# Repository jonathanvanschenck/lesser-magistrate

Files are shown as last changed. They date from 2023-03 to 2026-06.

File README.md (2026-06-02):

#  The Lesser Magistrate
A collection of Electrical and Mechanical Schematics for the IOC Lesser Magistrate Quizzing System

Schematics, PCB Files, BOM and 3D printing files are [available here](https://github.com/jonathanvanschenck/lesser-magistrate).

To find more information or get involved with Christian Bible Quizzing (CBQ), [click here](https://cbqz.org).

## Philosophy of Design
Heretofore, bible quizzing has had a fairly high barrier to entry; whether it be complicated rulebooks, distinct cultural practices or (of relevance here) expensive supplies. This project
seeks to address that third barrier by providing a low-cost, high-performance quizzing buzzer system, which can built by a reasonably competent individual. Unlike existing systems, we need
to meet the following design requirements:

  - Low cost and easily available parts
  - Easily manufactureable without special tooling
  - Is modular in design (e.g. individual components are easily and cheaply replaceable)
  - Can support up to 15 simultaneous participants

## Build Instructions
A Lesser Magistrate set can be built with a varying number of triggers depending on your needs. Throughout this documentation, examples are given for three common configurations:

- **16 triggers** — the maximum supported: 3 teams of 5 quizzers each, plus 1 trigger reserved for the quiz magistrate.
- **10 triggers** — the typical arrangement for a CBQ quiz: 3 teams of 3 quizzers each, plus 1 for the quiz magistrate.
- **12 triggers** — a 10-trigger set with 2 spares, useful to have on hand in case of hardware failure during a tournament.

If you have recieved a build kit, you should already have all the raw materials to build a lesser magistrate, including electrical components, 3d printed enclosures and hardware. In this case, you will only need a few tools to help during the build:
  - A Soldering Iron (literally anything will work here -- you don't need to spend tons of money on this unless you plan to make a lot of units)
  - Lead-free Solder (Again, literally anything will work here -- the amount of soldering on the project is pretty small so you won't run out)
  - Allen Wrench
  - Phillips head screw driver (long shaft)

### Video Guides and Examples

There is a video guide you can follow for step-by-step instructions on how to build your Lesser Magistrate system:

- https://www.youtube.com/watch?v=u-B20jy8v2o&list=PL-Vn05Kf5ezxIfupx7_Z1d6l5HKGBeLW2

Here are additional example videos:

- https://youtu.be/reuCWvhqvTU
- https://youtu.be/7Vi3QWguprs
- https://youtu.be/mlhh7Sf7_HU
- https://youtu.be/uHA6wKbFMOs
- https://youtu.be/KhpSTn409PQ
- https://youtu.be/kogF7mJOyTQ

### Electrical Schematics

All electrical schematics are available in the [graphics](./graphcis) directory, which can be helpful during assembly, particularly for those who are more electrically inclined.

There are some additional tools which are very helpful during the build process; but are not strictly necessary:
  - Some elmers glue, or similar light adhesive
  - The assembly jigs, [see the 3d printer directory for details](./3d)

If you are interested in purchasing a Lesser Magistrate system (or any of the necessary components -- particularly the PCBs), contact [the author](https://github.com/jonathanvanschenck).

If you did *not* receive a kit, the next section will explain how to acquire all the necessary raw components.

### Ordering the Components Yourself
If you did not receive kit, you will need to acquire the raw materials. Broadly there are 3 categories of things you will need to purchase:

#### 1. Electrical Component
You will need to buy all the electrical components (meaning chips, resistors, connectors and wires). See the [components README](./components/README.md) for full part lists and Digikey shopping links for 16, 12, and 10 trigger set configurations.

#### 2. PCB
You will also need to buy the actual PCBs to soulder everything to. You can find the gerber files (the extension is `.zip`) in the `gerber` directory, with a [README](./gerber/README.md) for details. You can use any PCB manufacturer you prefer, for example [PCBWay](https://www.pcbway.com/) -- in every case you cant just upload your gerber files and the website will walk you through the steps. Two things to note: (1) make sure to select HASL lead-free surface treatment to avoid lead exposure, use defaults for everything else (2) you will likely be required to order at least 5 of every board; but the boards are sufficiently cheap that shipping is frequently the majority of the PCB cost even when over-buying boards.

#### 3. Plastic Enclosures
You will also need to get plastic enclosures for all the electrical elements. All of this is done with a 3d printer. Many schools and libraries have 3d printers available to the students/members, so try asking around in your community to see if someone has access to a printer to help with this piece. There are also plenty of online services that you can upload a file to and have them print and ship it to you. Though, if you plan on making more than, like, 2 of these units -- just get a printer yourself. They are pretty cheap these days, can you can do a lot with them. Both [Bambu Labs](https://bambulab.com/en-us) and [Prusa Reaserch](https://www.prusa3d.com/) have mid-level and high-end hobbyist models in the $500-$1500 range.

However you plan on getting your prints, you will need the STL files in the [stl](./stl) directory -- see the README there for details.

## Contributing and Development
The Lesser Magistrate is a fully open sourced project, and as such contribution is encouraged! As such PRs are more than welcome, and we would love to hear about [any issues](https://github.com/jonathanvanschenck/lesser-magistrate/issues) you may run into. Feature requests are also encouraged -- though keep in mind features will only be included in this project if they conform to the Philosophy of Design described above. Finally, if you take this project and do something cool with it (like adding extra features not suitable to this design philosophy), we would love to hear about it so that we can add a link to your work in the section below!

Currently the electrical side of the project is developed in [diptrace](https://diptrace.com/), and all the project files are in the [lib](./lib) directory. That being said, we are in the process of converting to KiCAD as the development tool, and also creating a SMD-variant of the LM/LMM/Trigger boards which will facilitate a pick-n-place machine assembly; so don't get too attached to diptrace.

## Related Projects

## Deuteronomy 6:5-7
Love the Lord your God with all your heart and with all your soul and with all your strength.
These commandments that I give you today are to be on your hearts.
Impress them on your children. Talk about them when you sit at home and when you walk along the road, when you lie down and when you get up.

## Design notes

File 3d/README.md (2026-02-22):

# Enclosures and Construction Assests
This subdirectory contains all the stl files for the plastic enclosures for the electronics as well as jigs for assembly.

An STL file is the standard format used in the 3d printing world. So, if you are ordering out these parts, you can provide these STLs and
your manufacturer will know what to do with them.

Note, each set of files will create a single instance of whatever you are printing. So, for example, you will need a barrel, cap and stablizer to make 1 trigger. So if you want 16 triggers, you will need 16 stablizers, caps and barrrels.

## STL Files
The STL files for all 3d printed parts can be found in the `stl` folder. Contained are:
  - Enclosures:
    - LM Box:
        - [Top](./stl/LMBottom.stl)
        - [Bottom](./stl/LMBottom.stl)
    - LLM Box:
        - [Top](./stl/LMMTop.stl)
        - [Bottom](./stl/LLMBottom.stl)
    - Trigger:
        - [Barrel](./stl/TriggerBottom.stl)
        - [Cap](./stl/TriggerCap.stl): Important Note! You might need to scale this part up/down by a few percent during slicing so that you achieve an interference fit with the barrel.
        - [Stabilizer](./stl/TriggerStablizer.stl)
  - Jigs: These are optional assembly jigs, which are very nice if you are make many sets all together
    - [Board holder](./stl/LMConstructionBoardHolder.stl): used to hold the PCB in place while soldering.
    - Trigger jig:
        - [Anvil](./stl/TriggerConstructionAnvil.stl): creates a flat surface for the trigger to be pressed against.
        - [Ram](./stl/TriggerConstructionRam.stl): used to press the cap onto the barrel without hurting your hands.

When generating gcode with your slicer, it is recommended to use 0.2mm accuracy, rectilinear infill at 20% and print using PLA. Additionally, the trigger's cap may need to be scaled slightly (a few percent) in your slicer to achieve a good interference fit with the barrel.

## Quantities by Trigger Set

The number of printed parts depends on how many triggers you are building. Enclosure quantities scale with triggers; jigs are optional and quantity depends on your workflow.

### Enclosures

| STL File | 16 Trigger Set | 12 Trigger Set | 10 Trigger Set | Explanation |
|---|:---:|:---:|:---:|---|
| [LM Box Top](./stl/LMTop.stl) | 1 | 1 | 1 | One per set — top half of the main controller enclosure |
| [LM Box Bottom](./stl/LMBottom.stl) | 1 | 1 | 1 | One per set — bottom half of the main controller enclosure |
| [LMM Box Top](./stl/LMMTop.stl) | 3 | 3 | 3 | One per team (3 teams in every configuration) |
| [LMM Box Bottom](./stl/LLMBottom.stl) | 3 | 3 | 3 | One per team (3 teams in every configuration) |
| [Trigger Barrel](./stl/TriggerBottom.stl) | 16 | 12 | 10 | One per trigger |
| [Trigger Cap](./stl/TriggerCap.stl) | 16 | 12 | 10 | One per trigger — may need slight scaling for interference fit |
| [Trigger Stabilizer](./stl/TriggerStablizer.stl) | 16 | 12 | 10 | One per trigger |

### Assembly Jigs (Optional)

| STL File | Suggested Qty | Explanation |
|---|:---:|---|
| [Board Holder](./stl/LMConstructionBoardHolder.stl) | 1 | Holds the PCB steady during soldering; one is sufficient for any set size |
| [Trigger Jig Anvil](./stl/TriggerConstructionAnvil.stl) | 1 | Flat surface for pressing caps onto barrels; one is sufficient |
| [Trigger Jig Ram](./stl/TriggerConstructionRam.stl) | 1 | Used with the anvil to press caps without hand strain; one is sufficient |

Contact [the author](https://github.com/jonathanvanschenck/) for further details.

## CAD Files
The full CAD files can be found on onshape:
  - [The main box](https://cad.onshape.com/documents/543b25c417126967cb08de50/v/1616035887736616c0c97bd4/e/729fc64504c2a798e70d9855).
  - [The module](https://cad.onshape.com/documents/a71d7e6c5d369e82da67ce55/v/a1a71b7b6bb9f6b15cbdba2f/e/51fbe87dbc7215f3dbb1e72c).
  - [The trigger](https://cad.onshape.com/documents/fc78aac2c958586ca1177853/w/f2e33e2147721cb4fc4541b8/e/58d502121f0acd43c261de76).
  - [Trigger jig](https://cad.onshape.com/documents/b3dc0fd1912a70c055d7c740/w/58a53ed1eda9de1b411d2abd/e/50ec51447436c03dc649d699)
  - [Board holder jig](https://cad.onshape.com/documents/089ddd3080857b092a4a133b/w/d44446d03ada5b263a56f82f/e/a523e0c8f14e67229ecee9d0)

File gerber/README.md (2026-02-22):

# Gerber Files
In this directory are the gerber files (extension `.zip`) for the PCBs used in this project.

A gerber file is really just a zip file containing all the information necessary for a PCB manufacturer to create your PCB. Any boardhouse will know what to do with a gerber file.

Note, each file will create only a single instance of whatever it contains. So, for example, if you order "a LMM board" from the gerber file, you will get exactly 1 PCB, where a typical set requires 3. So, you will want to make sure your quantities are corrected when ordering.

## Gerber files
  - [LM Board](./LMGerber.zip)
  - [LMM Board](./LMMGerber.zip)
  - [Trigger Board](./TriggerGerber.zip)

## Quantities by Trigger Set

The number of PCBs you need to order depends on how many triggers you are building. There is always 1 LM (main controller) board and 1 LMM (module) board per team. The number of Trigger boards equals the total number of triggers.

| Gerber File | 16 Trigger Set | 12 Trigger Set | 10 Trigger Set | Explanation |
|---|:---:|:---:|:---:|---|
| [LM Board](./LMGerber.zip) | 1 | 1 | 1 | One per set — the main quiz magistrate controller board |
| [LMM Board](./LMMGerber.zip) | 3 | 3 | 3 | One per team |
| [Trigger Board](./TriggerGerber.zip) | 16 | 12 | 10 | One per trigger |

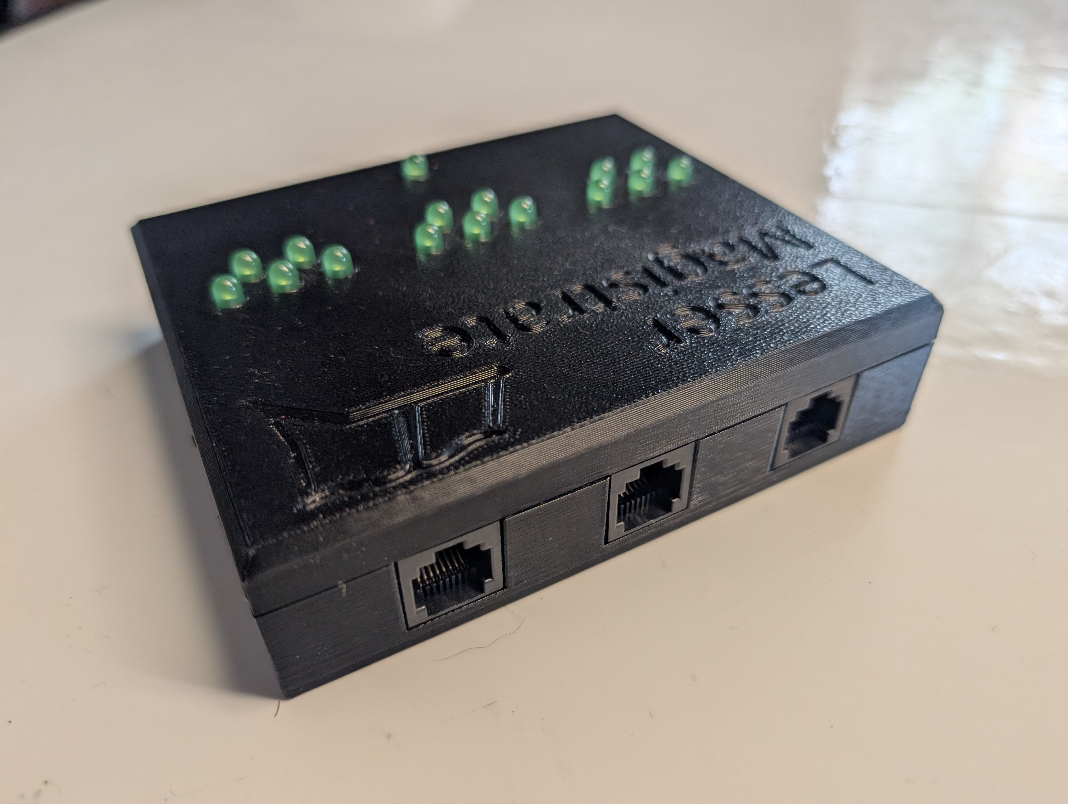
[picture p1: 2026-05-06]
images/2_lm_console_back.jpg

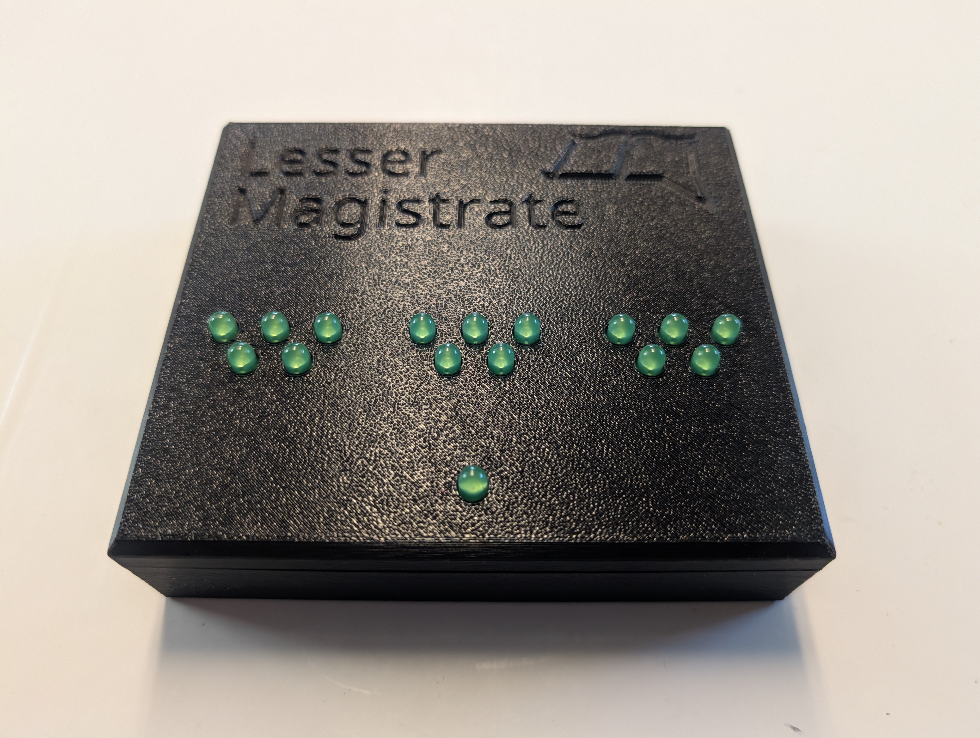
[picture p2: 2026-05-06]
images/0_lm_console.jpg

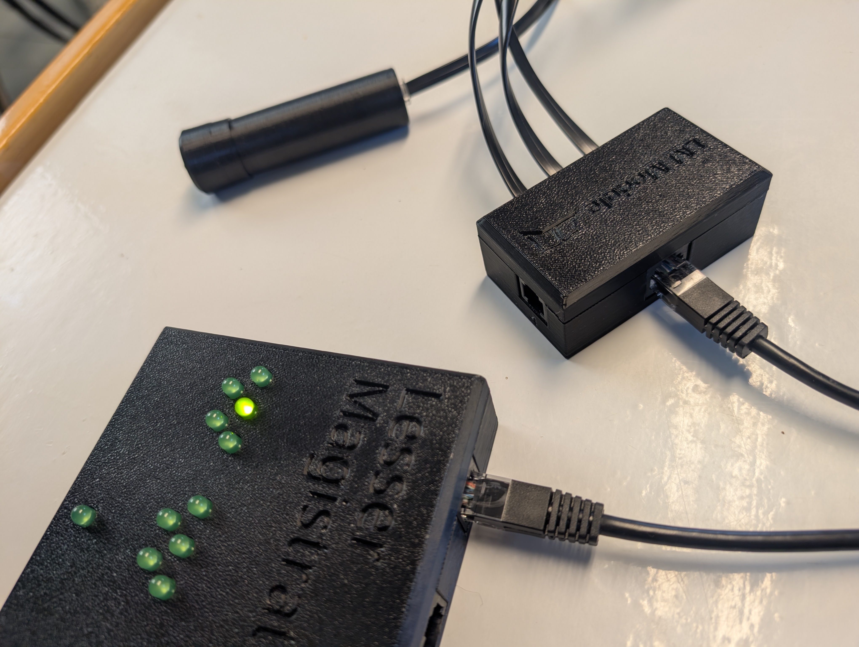
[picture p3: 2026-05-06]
images/8_lm_junction_plugged.jpg

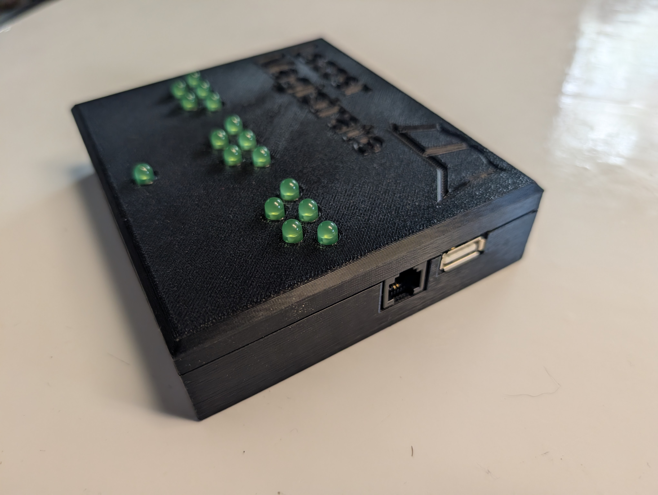
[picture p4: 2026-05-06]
images/1_lm_console_side.jpg

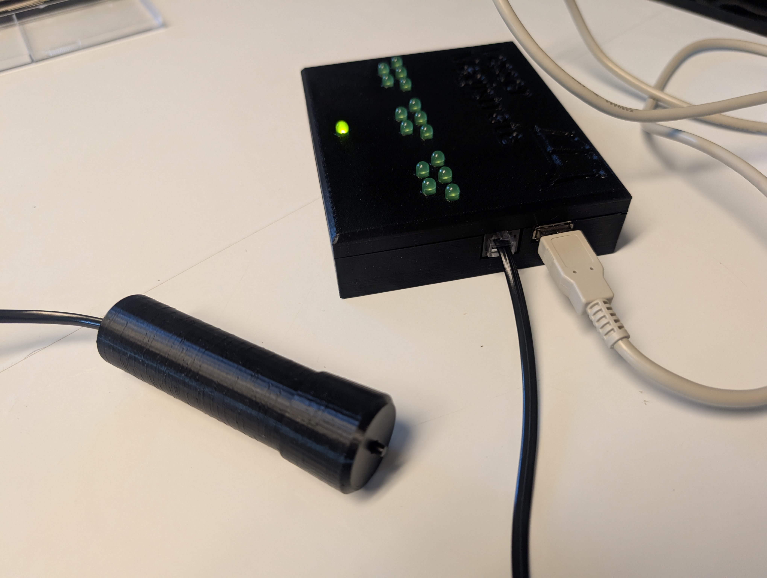
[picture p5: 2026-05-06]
images/5_lm_console_reset_plugged.jpg

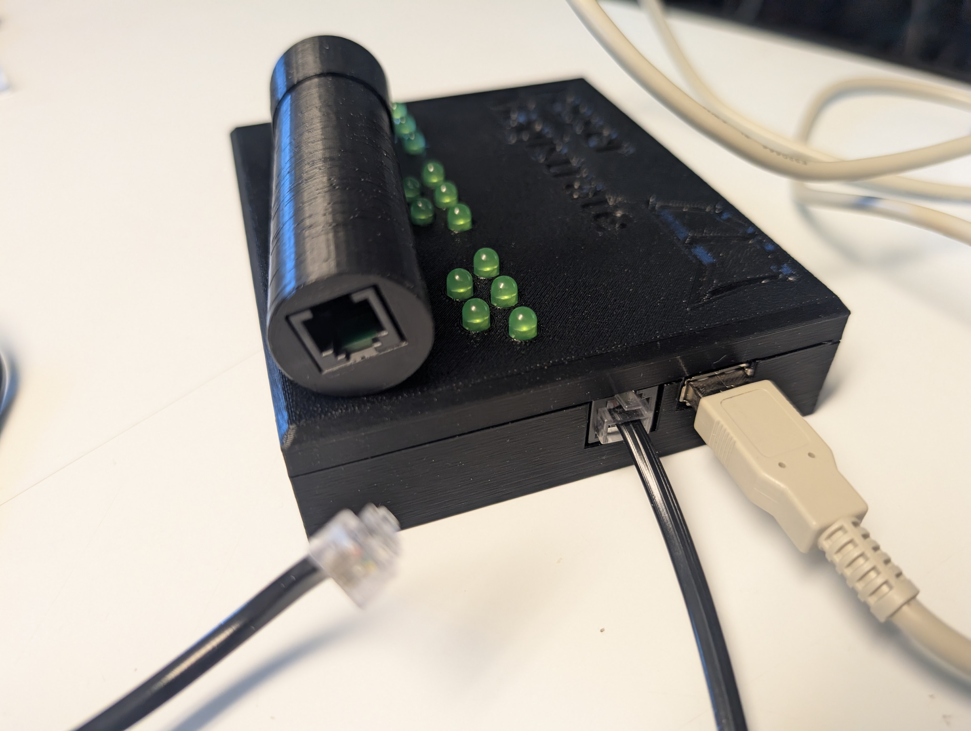
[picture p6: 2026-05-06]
images/4_lm_console_reset.jpg

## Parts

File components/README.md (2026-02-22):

# Electrical Components
This document describes all the electrical components that you will need to create a lesser magistrate unit.

## 16 Trigger Set
This section assume you want a full 16 trigger set (3 teams of 5 quizzers plus 1 quiz magistrate).

A digikey shopping list is [provided here](https://www.digikey.com/en/mylists/list/F2CUTMZWMI)

| # | Part Number | Qty | Qty description | Description | Order Link | Alternates |
|---|---|-----| ---|---|---|---|
| 1 | L513GD-B | 15 | LM | GREEN LED | [2460-L513GD-B-ND](https://www.digikey.com/en/products/detail/american-opto-plus-led/L513GD-B/13556882) | — |
| 2 | L513YD-C | 1 | LM | YELLOW LED | [2460-L513YD-C-ND](https://www.digikey.com/en/products/detail/american-opto-plus-led/L513YD-C/13556895) | — |
| 3 | 4610X-101-151LF | 2 | LM | RES ARRAY 9 RES 150 OHM 10SIP (for LED current limiting) | [4610X-1-151LF-ND](https://www.digikey.com/en/products/detail/bourns-inc/4610X-101-151LF/1089176) | — |
| 4 | 4608X-102-330LF | 4 | LM | RES ARRAY 4 RES 33 OHM 8SIP (for trigger signal input isolation) | [4608X-2-330LF-ND](https://www.digikey.com/en/products/detail/bourns-inc/4608X-102-330LF/1089133) | — |
| 5 | 4610X-101-103LF | 2 | LM | RES ARRAY 9 RES 10K OHM 10SIP (pull down) | [4610X-1-103LF-ND](https://www.digikey.com/en/products/detail/bourns-inc/4610X-101-103LF/1089169) | — |
| 6 | C410C105K3R5TA | 3 | LM | CAPACITOR CER 1UF (Stablizing) | [399-C410C105K3R5TA-ND](https://www.digikey.com/en/products/detail/kemet/C410C105K3R5TA/12701220) | — |
| 7 | C410C103K5R5TA | 15 | LM | CAPACITOR CER 10000PF (Isolating) | [399-C410C103K5R5TA-ND](https://www.digikey.com/en/products/detail/kemet/C410C103K5R5TA/12701142) | — |
| 8 | CD74AC04E | 1 | LM | IC INVERTER (NOT Gate) 6CH 1IN 14DIP | [296-4217-5-ND](https://www.digikey.com/en/products/detail/texas-instruments/CD74AC04E/375681) | — |
| 9 | CD4072BE | 3 | LM | IC OR Gate 2CH 4-INP 14DIP | [296-2063-5-ND](https://www.digikey.com/en/products/detail/texas-instruments/CD4072BE/67317) | — |
| 10 | SN74AC573N | 2 | LM | IC D-Latch 8:8 20-PDIP | [296-33649-5-ND](https://www.digikey.com/en/products/detail/texas-instruments/SN74AC573N/1575944) | — |
| 11 | MTJ-881X1 | 6 | 3 LM, 1 per LMM (3 total) | RJ45 Connector 8P8C | [2057-MTJ-881X1-ND](https://www.digikey.com/en/products/detail/adam-tech/MTJ-881X1/9832263) | — |
| 12 | USB-A1HSB6 | 1 | LM | USB A Connector | [ED2990-ND](https://www.digikey.com/en/products/detail/on-shore-technology-inc/USB-A1HSB6/2677751) | — |
| 13 | 54601-906001WPLF *(Obsoleted: may be hard to find)* | 32 | 1 per LM, 5 per LMM (15 total), 1 per Trigger (16 total) | RJ11 Connector 6P2C | [609-5354-ND](https://www.digikey.com/en/products/detail/amphenol-cs-fci/54601-906001WPLF/4242889) | [87180-062LF](https://www.digikey.com/en/products/detail/amphenol-cs-fci/87180-062LF/1001369) (more expensive and deeper socket), [E5362-3000G2-L](https://www.digikey.com/en/products/detail/pulse-electronics/E5362-3000G2-L/2264740) (connector is vertically mirrored), [E5362-300NG2-L](https://www.digikey.com/en/products/detail/pulse-electronics/E5362-300NG2-L/1785183) (grey instead of black) |
| 14 | AK670/2-1 | 1 | LM |USB Cable A TO A, Male to Male | [AE1454-ND](https://www.digikey.com/en/products/detail/assmann-wsw-components/AK670-2-1/930239) | — |
| 15 | N002-015-BK | 3 | 1 per LMM (3 total) | Ethernect Cable 8P8C 15' | [TL573-ND](https://www.digikey.com/en/products/detail/eaton-tripp-lite/N002-015-BK/4438389) | — |
| 16 | AT-S-26-6/6/B-7/R | 16 | 1 per Trigger (16 total) | RJ11 Cable 6P6C 7' | [A2662R-07-ND](https://www.digikey.com/en/products/detail/assmann-wsw-components/AT-S-26-6-6-B-7-R/1972588) | — |
| 17 | TS11-674-95-BK-260-RA-D | 16 | 1 per Trigger (16 total) | TACTILE Button SPST-NO | [2223-TS11-674-95-BK-260-RA-D-ND](https://www.digikey.com/en/products/detail/same-sky-formerly-cui-devices/TS11-674-95-BK-260-RA-D/16562778) | — |

## 12 Trigger Set
This section assume you want a 12 trigger set (3 teams of 3 quizzers plus 1 quiz magistrate plus 2 spares).

A digikey shopping list is [provided here](https://www.digikey.com/en/mylists/list/Z0QW9PNE1D)
| # | Part Number | Qty | Qty description | Description | Order Link | Alternates |
|---|---|-----| ---|---|---|---|
| 1 | L513GD-B | 15 | LM | GREEN LED | [2460-L513GD-B-ND](https://www.digikey.com/en/products/detail/american-opto-plus-led/L513GD-B/13556882) | — |
| 2 | L513YD-C | 1 | LM | YELLOW LED | [2460-L513YD-C-ND](https://www.digikey.com/en/products/detail/american-opto-plus-led/L513YD-C/13556895) | — |
| 3 | 4610X-101-151LF | 2 | LM | RES ARRAY 9 RES 150 OHM 10SIP (for LED current limiting) | [4610X-1-151LF-ND](https://www.digikey.com/en/products/detail/bourns-inc/4610X-101-151LF/1089176) | — |
| 4 | 4608X-102-330LF | 4 | LM | RES ARRAY 4 RES 33 OHM 8SIP (for trigger signal input isolation) | [4608X-2-330LF-ND](https://www.digikey.com/en/products/detail/bourns-inc/4608X-102-330LF/1089133) | — |
| 5 | 4610X-101-103LF | 2 | LM | RES ARRAY 9 RES 10K OHM 10SIP (pull down) | [4610X-1-103LF-ND](https://www.digikey.com/en/products/detail/bourns-inc/4610X-101-103LF/1089169) | — |
| 6 | C410C105K3R5TA | 3 | LM | CAPACITOR CER 1UF (Stablizing) | [399-C410C105K3R5TA-ND](https://www.digikey.com/en/products/detail/kemet/C410C105K3R5TA/12701220) | — |
| 7 | C410C103K5R5TA | 15 | LM | CAPACITOR CER 10000PF (Isolating) | [399-C410C103K5R5TA-ND](https://www.digikey.com/en/products/detail/kemet/C410C103K5R5TA/12701142) | — |
| 8 | CD74AC04E | 1 | LM | IC INVERTER (NOT Gate) 6CH 1IN 14DIP | [296-4217-5-ND](https://www.digikey.com/en/products/detail/texas-instruments/CD74AC04E/375681) | — |
| 9 | CD4072BE | 3 | LM | IC OR Gate 2CH 4-INP 14DIP | [296-2063-5-ND](https://www.digikey.com/en/products/detail/texas-instruments/CD4072BE/67317) | — |
| 10 | SN74AC573N | 2 | LM | IC D-Latch 8:8 20-PDIP | [296-33649-5-ND](https://www.digikey.com/en/products/detail/texas-instruments/SN74AC573N/1575944) | — |
| 11 | MTJ-881X1 | 6 | 3 LM, 1 per LMM (3 total) | RJ45 Connector 8P8C | [2057-MTJ-881X1-ND](https://www.digikey.com/en/products/detail/adam-tech/MTJ-881X1/9832263) | — |
| 12 | USB-A1HSB6 | 1 | LM | USB A Connector | [ED2990-ND](https://www.digikey.com/en/products/detail/on-shore-technology-inc/USB-A1HSB6/2677751) | — |
| 13 | 54601-906001WPLF *(Obsoleted: may be hard to find)* | 28 | 1 per LM, 5 per LMM (15 total), 1 per Trigger (12 total) | RJ11 Connector 6P2C | [609-5354-ND](https://www.digikey.com/en/products/detail/amphenol-cs-fci/54601-906001WPLF/4242889) | [87180-062LF](https://www.digikey.com/en/products/detail/amphenol-cs-fci/87180-062LF/1001369) (more expensive and deeper socket), [E5362-3000G2-L](https://www.digikey.com/en/products/detail/pulse-electronics/E5362-3000G2-L/2264740) (connector is vertically mirrored), [E5362-300NG2-L](https://www.digikey.com/en/products/detail/pulse-electronics/E5362-300NG2-L/1785183) (grey instead of black) |
| 14 | AK670/2-1 | 1 | LM |USB Cable A TO A, Male to Male | [AE1454-ND](https://www.digikey.com/en/products/detail/assmann-wsw-components/AK670-2-1/930239) | — |
| 15 | N002-015-BK | 3 | 1 per LMM (3 total) | Ethernect Cable 8P8C 15' | [TL573-ND](https://www.digikey.com/en/products/detail/eaton-tripp-lite/N002-015-BK/4438389) | — |
| 16 | AT-S-26-6/6/B-7/R | 12 | 1 per Trigger (12 total) | RJ11 Cable 6P6C 7' | [A2662R-07-ND](https://www.digikey.com/en/products/detail/assmann-wsw-components/AT-S-26-6-6-B-7-R/1972588) | — |
| 17 | TS11-674-95-BK-260-RA-D | 12 | 1 per Trigger (12 total) | TACTILE Button SPST-NO | [2223-TS11-674-95-BK-260-RA-D-ND](https://www.digikey.com/en/products/detail/same-sky-formerly-cui-devices/TS11-674-95-BK-260-RA-D/16562778) | — |

## 10 Trigger Set
This section assume you want a 10 trigger set (3 teams of 3 quizzers plus 1 quiz magistrate).

A digikey shopping list is [provided here](https://www.digikey.com/en/mylists/list/SJFN28F6PZ)

| # | Part Number | Qty | Qty description | Description | Order Link | Alternates |
|---|---|-----| ---|---|---|---|
| 1 | L513GD-B | 15 | LM | GREEN LED | [2460-L513GD-B-ND](https://www.digikey.com/en/products/detail/american-opto-plus-led/L513GD-B/13556882) | — |
| 2 | L513YD-C | 1 | LM | YELLOW LED | [2460-L513YD-C-ND](https://www.digikey.com/en/products/detail/american-opto-plus-led/L513YD-C/13556895) | — |
| 3 | 4610X-101-151LF | 2 | LM | RES ARRAY 9 RES 150 OHM 10SIP (for LED current limiting) | [4610X-1-151LF-ND](https://www.digikey.com/en/products/detail/bourns-inc/4610X-101-151LF/1089176) | — |
| 4 | 4608X-102-330LF | 4 | LM | RES ARRAY 4 RES 33 OHM 8SIP (for trigger signal input isolation) | [4608X-2-330LF-ND](https://www.digikey.com/en/products/detail/bourns-inc/4608X-102-330LF/1089133) | — |
| 5 | 4610X-101-103LF | 2 | LM | RES ARRAY 9 RES 10K OHM 10SIP (pull down) | [4610X-1-103LF-ND](https://www.digikey.com/en/products/detail/bourns-inc/4610X-101-103LF/1089169) | — |
| 6 | C410C105K3R5TA | 3 | LM | CAPACITOR CER 1UF (Stablizing) | [399-C410C105K3R5TA-ND](https://www.digikey.com/en/products/detail/kemet/C410C105K3R5TA/12701220) | — |
| 7 | C410C103K5R5TA | 15 | LM | CAPACITOR CER 10000PF (Isolating) | [399-C410C103K5R5TA-ND](https://www.digikey.com/en/products/detail/kemet/C410C103K5R5TA/12701142) | — |
| 8 | CD74AC04E | 1 | LM | IC INVERTER (NOT Gate) 6CH 1IN 14DIP | [296-4217-5-ND](https://www.digikey.com/en/products/detail/texas-instruments/CD74AC04E/375681) | — |
| 9 | CD4072BE | 3 | LM | IC OR Gate 2CH 4-INP 14DIP | [296-2063-5-ND](https://www.digikey.com/en/products/detail/texas-instruments/CD4072BE/67317) | — |
| 10 | SN74AC573N | 2 | LM | IC D-Latch 8:8 20-PDIP | [296-33649-5-ND](https://www.digikey.com/en/products/detail/texas-instruments/SN74AC573N/1575944) | — |
| 11 | MTJ-881X1 | 6 | 3 LM, 1 per LMM (3 total) | RJ45 Connector 8P8C | [2057-MTJ-881X1-ND](https://www.digikey.com/en/products/detail/adam-tech/MTJ-881X1/9832263) | — |
| 12 | USB-A1HSB6 | 1 | LM | USB A Connector | [ED2990-ND](https://www.digikey.com/en/products/detail/on-shore-technology-inc/USB-A1HSB6/2677751) | — |
| 13 | 54601-906001WPLF *(Obsoleted: may be hard to find)* | 26 | 1 per LM, 5 per LMM (15 total), 1 per Trigger (10 total) | RJ11 Connector 6P2C | [609-5354-ND](https://www.digikey.com/en/products/detail/amphenol-cs-fci/54601-906001WPLF/4242889) | [87180-062LF](https://www.digikey.com/en/products/detail/amphenol-cs-fci/87180-062LF/1001369) (more expensive and deeper socket), [E5362-3000G2-L](https://www.digikey.com/en/products/detail/pulse-electronics/E5362-3000G2-L/2264740) (connector is vertically mirrored), [E5362-300NG2-L](https://www.digikey.com/en/products/detail/pulse-electronics/E5362-300NG2-L/1785183) (grey instead of black) |
| 14 | AK670/2-1 | 1 | LM |USB Cable A TO A, Male to Male | [AE1454-ND](https://www.digikey.com/en/products/detail/assmann-wsw-components/AK670-2-1/930239) | — |
| 15 | N002-015-BK | 3 | 1 per LMM (3 total) | Ethernect Cable 8P8C 15' | [TL573-ND](https://www.digikey.com/en/products/detail/eaton-tripp-lite/N002-015-BK/4438389) | — |
| 16 | AT-S-26-6/6/B-7/R | 10 | 1 per Trigger (10 total) | RJ11 Cable 6P6C 7' | [A2662R-07-ND](https://www.digikey.com/en/products/detail/assmann-wsw-components/AT-S-26-6-6-B-7-R/1972588) | — |
| 17 | TS11-674-95-BK-260-RA-D | 10 | 1 per Trigger (10 total) | TACTILE Button SPST-NO | [2223-TS11-674-95-BK-260-RA-D-ND](https://www.digikey.com/en/products/detail/same-sky-formerly-cui-devices/TS11-674-95-BK-260-RA-D/16562778) | — |

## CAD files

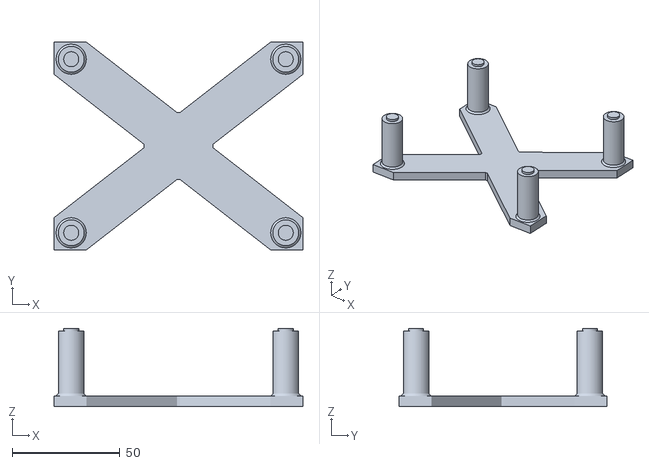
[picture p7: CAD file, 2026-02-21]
3d/stl/LMConstructionBoardHolder.stl
115.7 x 96.6 x 36.3

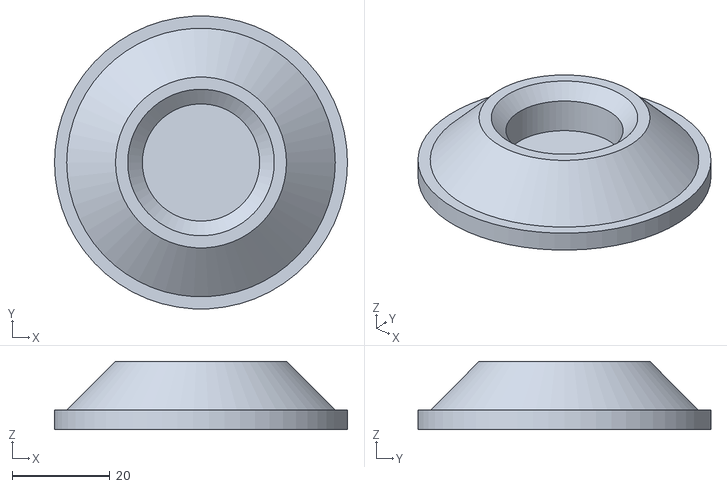
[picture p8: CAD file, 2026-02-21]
3d/stl/TriggerConstructionAnvil.stl
60.0 x 59.9 x 14.0

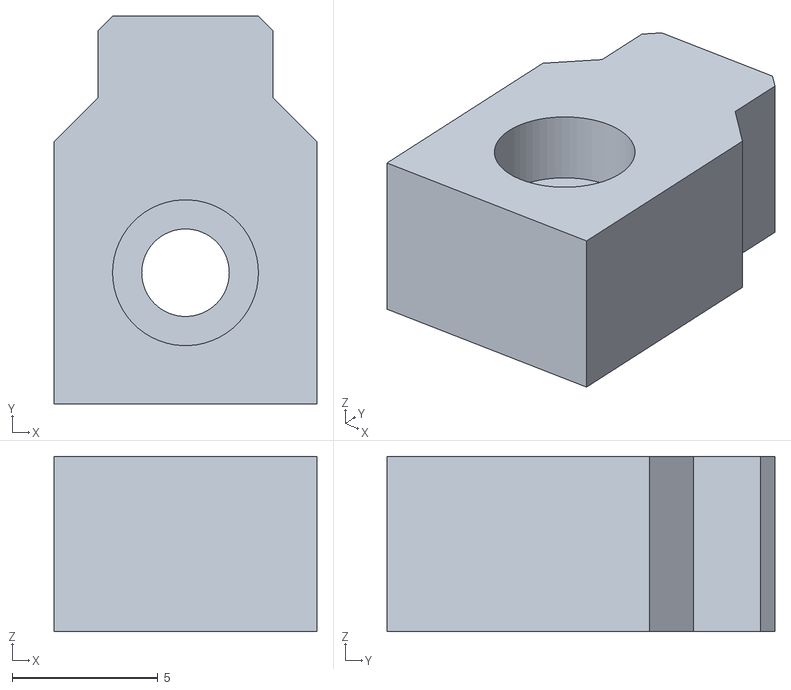
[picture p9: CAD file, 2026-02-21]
3d/stl/TriggerStablizer.stl
9.00 x 13.3 x 6.00

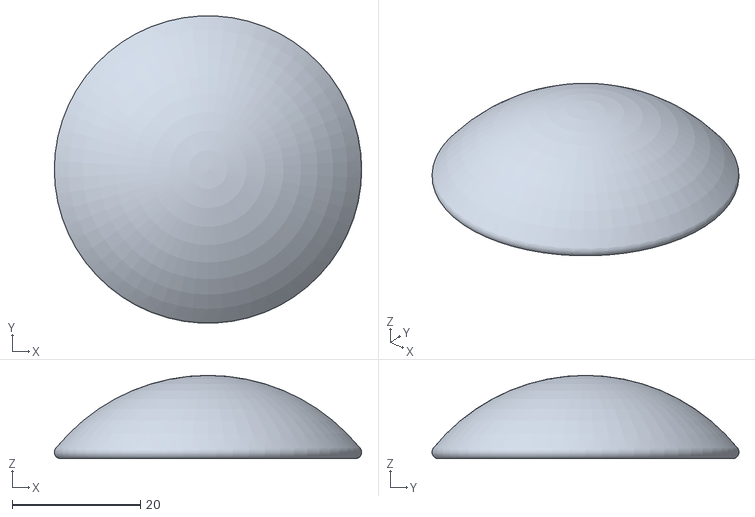
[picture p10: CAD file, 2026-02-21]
3d/stl/TriggerConstructionRam.stl
48.0 x 47.9 x 13.0

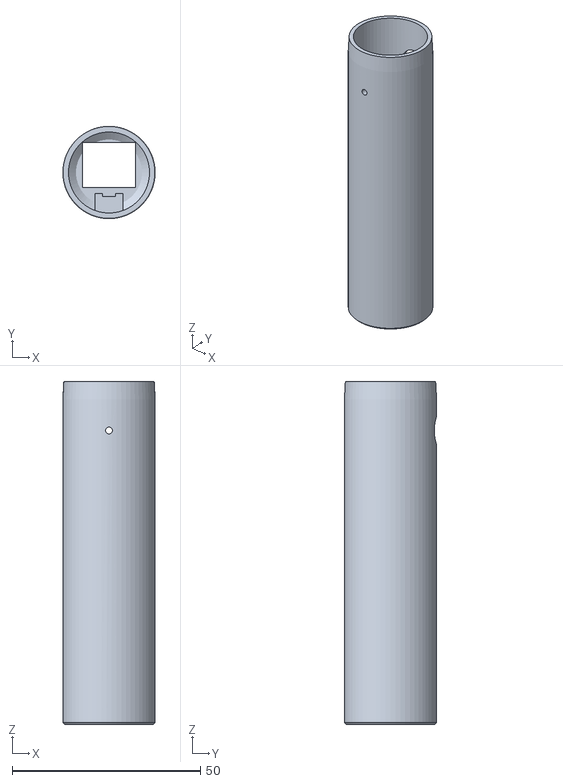
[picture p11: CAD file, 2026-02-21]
3d/stl/TriggerBottom.stl
24.5 x 24.5 x 91.0

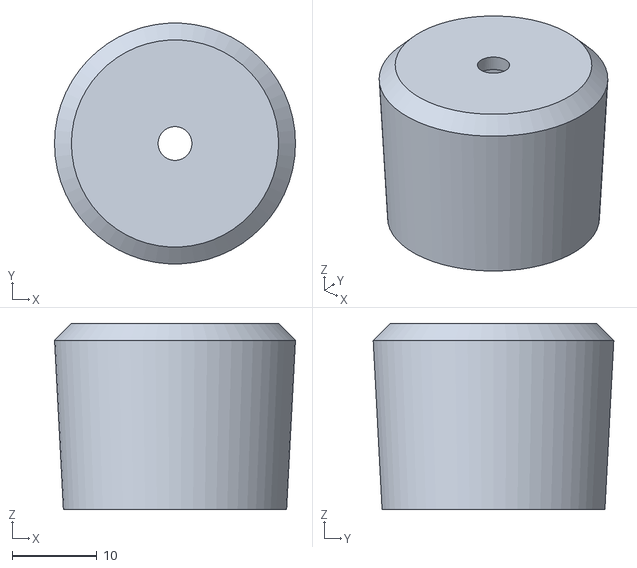
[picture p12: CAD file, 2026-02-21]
3d/stl/TriggerCap.stl
28.5 x 28.5 x 22.0

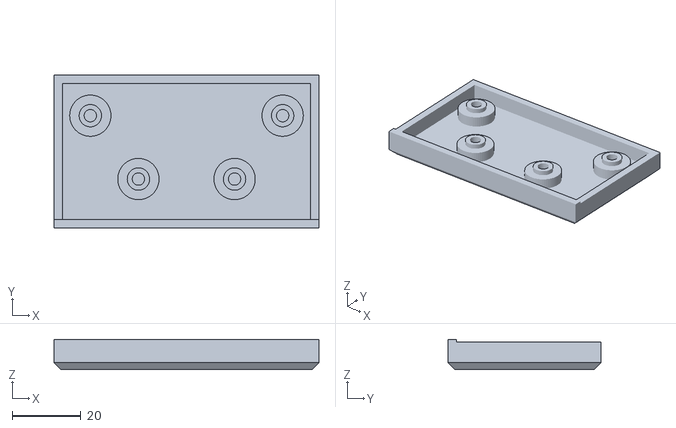
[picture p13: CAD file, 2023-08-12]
3d/stl/LMMTop.stl
77.0 x 44.5 x 8.78

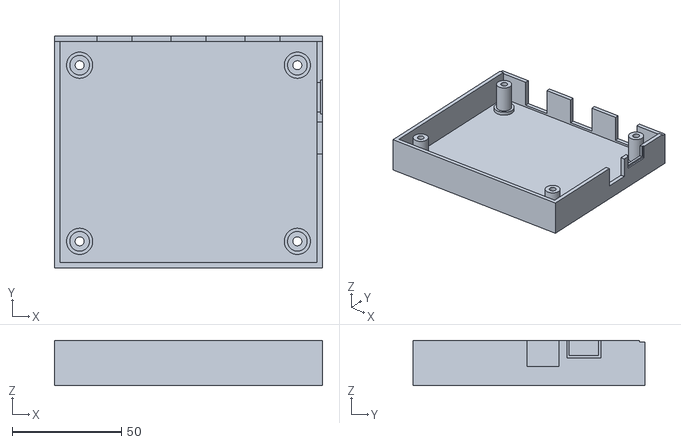
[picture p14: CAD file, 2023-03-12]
3d/stl/LMBottom.stl
122.7 x 106.0 x 20.8

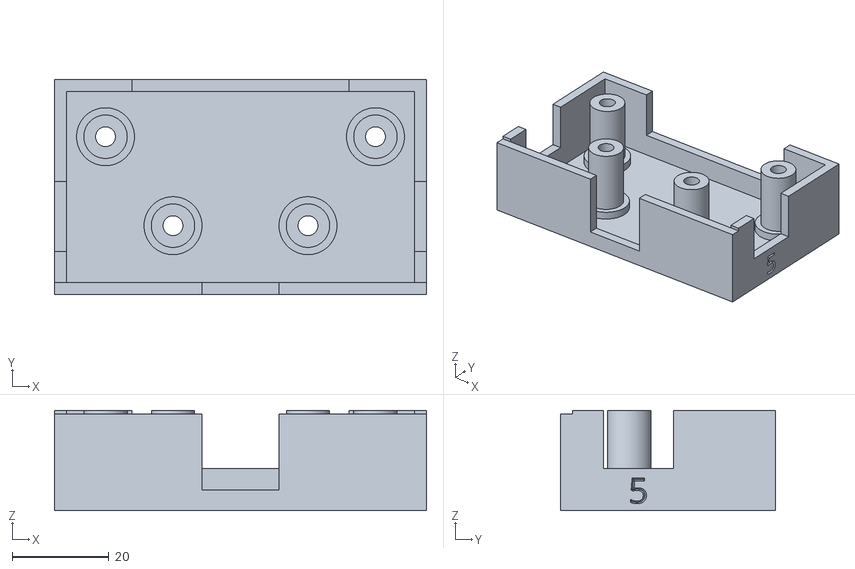
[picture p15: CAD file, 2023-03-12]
3d/stl/LMMBottom.stl
77.0 x 44.5 x 20.8

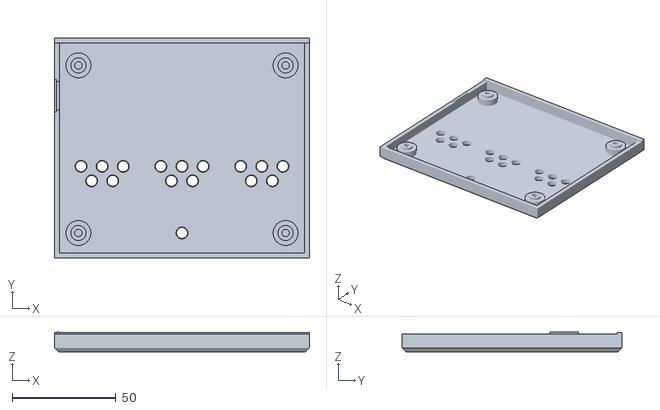
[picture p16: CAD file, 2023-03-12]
3d/stl/LMTop.stl
122.7 x 106.0 x 9.60

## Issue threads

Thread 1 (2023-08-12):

Twist inserting trigger plug can lead to shorts

jonathanvanschenck, 2023-08-12:
During the final stage of constructing the hand triggers/buzzers, some assemblers have found that the twisting action of inserting the bottom 3d printed plug in for gluing can cause the bent-apart RJ11 contacts to be twisted together. This shorts out the linear switch -- making the buzzer effectively "always on". This can be mitigated by wrapping the exposed metal of the contact/solder/wire with electrical tape or heat shrink tubing.

jonathanvanschenck, 2023-08-12:
Presumptive fix: redesign triggers to use a PCB instead of wires-soldered-to-contacts

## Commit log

2023-02-12 Fix mounting hole positioning
2023-02-12 Add enclosure links
2023-03-12 Fix trace routing bug on NOT gate
2023-03-12 Add stl files
    [BuzzerBottomLeft.stl, BuzzerBottomRight.stl, BuzzerTop.stl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]
2023-08-12 Update readme/bom
    [LMMTop.stl]
2026-02-21 Update 3d files for trigger v3
    [BuzzerBottomLeft.stl, BuzzerBottomRight.stl, BuzzerTop.stl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]
2026-02-21 Add gerber files
